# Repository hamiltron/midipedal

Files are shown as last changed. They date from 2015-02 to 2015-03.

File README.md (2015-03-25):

# Arduino One-Octave Foot Pedal MIDI Controller

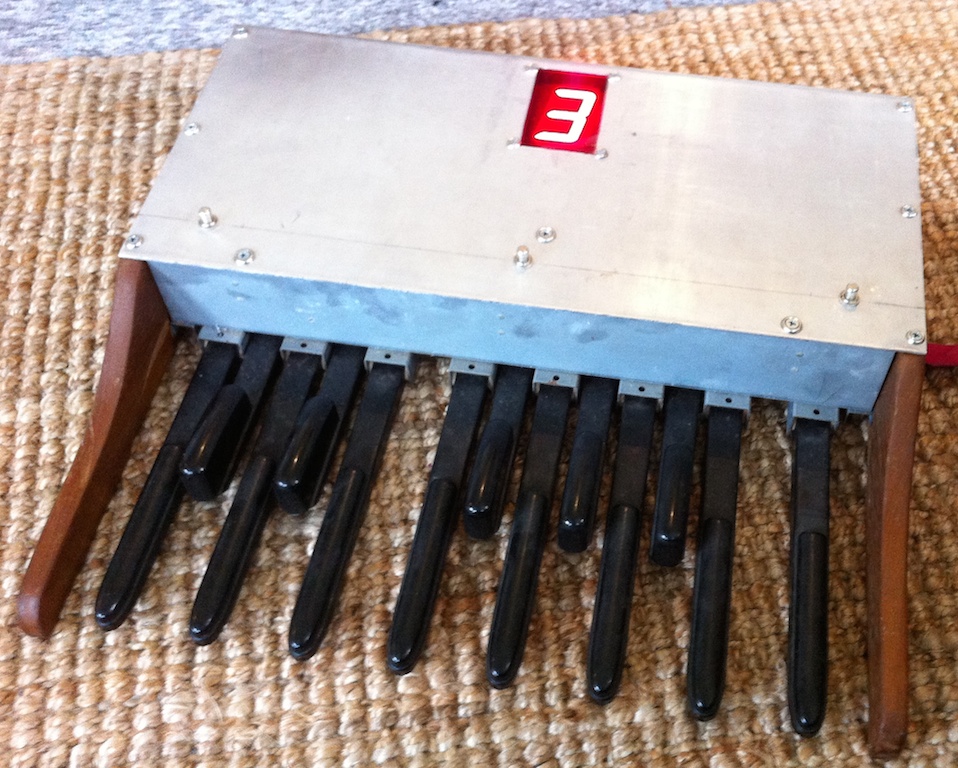
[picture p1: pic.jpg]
pic of pedal


## License

MIT

If you really need to rip this off for a commercial application, consider hiring me instead. :wink:

## Hardware 

I've written this for the [Arduino Micro](http://arduino.cc/en/Main/ArduinoBoardMicro). 
(Thus, the use of Serial1 for the MIDI output.) 

It has a one-octave foot pedal set 
with reed switches form a 70's era electronic organ. There are also an 'octave up', 'octave down', 
and 'configure' stomp switches, bringing the total switch count to 16 which makes for a tidy 4 x 4 
switch matrix. This uses the very nice [keypad library](http://playground.arduino.cc/Code/Keypad)
to manage the scanning and hold detection. In contrast to what is mentioned in the keypad 
documentation, diodes are a necessity for this type of application (one per switch) or you may get ghosting. 

There's a seven-segment display to show the octave and channel number. 
The decimal point is used to indicate polyphonic mode. 
The driver is the [TLC5916](http://www.ti.com/product/tlc5916) which is a snap to use over the SPI interface 
plus two extra Arduino outputs for the ~OE and LE pins. The current set resistor is 1K Ohm for 
approximately 20mA. 
The display I used is the Kingbright SA23-12SRWA which is about 6 cm high. It's nice and big and RED. 
**Rant**: Yes, blue LED's are new and therefore prejudicially cool, and red LED's are dusty old hat. 
But the reality 
is that human eyes disperse blue light more that red (the reason a lot of sunglasses have yellow tint) 
and these blue LED displays often have impressive 
luminosity which when combined, turn what would otherwise be a number into a fuzzy blue blob, 
leaving my microwave clock unreadable unless you're standing right in front of it. 

This seven segment display requires around 7.4 V to drive the segment diode strings, 
so we need a boost which is 
done with the old [MC34063](http://www.ti.com/product/mc34063a) (aka MC33063) 
which has very low frequency compared to modern switching regulators but there's a 
very nifty [part value calculator](http://www.nomad.ee/micros/mc34063a/). 
I doubled checked the calculated values with a spreadsheet based 
on the datasheet design equations and they all matched close enough for confidence. The intended output
voltage is about 9 V as this should give the needed 7.4 V for the LED's plus the TLC5916 output drop of 
about 1 V plus a small margin. This can be adjusted a bit if the display forward voltage deviates from 
the expected value. 

For the 5 V needed to drive the Atmel CPU, I decided to use the MCP1702 (5 V version) which supplies
a max current of 250 mA (completely fine for this application) with a typical dropout of 0.33 V. This is a 
much safer bet that using the onboard NCP1117 which has a spec'd dropout of 1.2 V 
(granted, at much higher currrent) and even though the CPU will probably run fine with a little less than 
5 V, having a roughly 0.4 V dropout gives much better margin of safety plus better mileage 
from the batteries. 

## UI

### Normal Mode

In any mode, the pedals trigger MIDI notes on the set octave and channel. In monophonic mode, the latest
pedal pressed triggers a note and the previous note is automatically silenced. In polyphonic mode, any 
number of notes may be triggered at once. (Technically this is not true as the keypad library keeps an
internal list of modified keys and it's default max size is ten, though this could easily be changed.) 
When in normal mode, the octave up and down switches move the octave and display is briefly on the 
display which also indicated whether or not polyphonic mode is enabled with the decimal point. 
Pressing the center 'configure' button briefly will also flash the display with the current channel.

**NOTE**: The octave and channel display (see below) are in zero-indexed hex, 
which departs from the convention of numbering MIDI channels 1 - 16, but this doesn't bother me
for personal uses so I'll leave it as such. 

### Configure Mode

If the configure button is held down for a few seconds, the controller will enter the configure mode, and the 
display will flash the current MIDI channel. Pressing the octave up and down buttons will change the 
MIDI channel and pressing the configure button will switch between polyphonic and monophonic mode
when the button is released. 
Pressing and holding the configure button will return to normal mode. 

### Non-Volatile Memory 

The current octave, channel, and poly/monophonic settings are stored in EEPROM each time they are
changed so the configuration is retained when the controller is switched off.

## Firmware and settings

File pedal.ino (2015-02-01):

#include <Keypad.h>
#include <EEPROM.h>
#include <SPI.h>

#define NOTE_OFF (0)
#define NOTE_ON  (1)

#define MONO (0)
#define POLY (1)

#define EE_ADDR_OCTAVE  (0)
#define EE_ADDR_POLY    (1)
#define EE_ADDR_CHANNEL (2)

#define VELOCITY (127)
#define HIGH_OCTAVE (9)

#define DOWN_BUTTON   (0x1D)
#define CONFIG_BUTTON (0x1E)
#define UP_BUTTON     (0x1F)

#define DEBOUNCE_MS     (10)
#define HOLD_MS         (2000)
#define FLASH_MS        (2000)
#define BLINK_PERIOD_MS (500)

#define TLC5916_OE (A5)
#define TLC5916_LE (A4)

// This utility macro function takes a key (0 = c, 1 = c#, 2 = b, etc) 
//   and the octave number and returns a valid midi note number
//   Not that for efficiency, it does not bounds check. 
#define MIDI_NOTE_NUM(key, octave) (key - 0x10 + 12 * octave)

enum states {
  NORMAL, 
  OCT_DOWN_PRESSED, 
  OCT_UP_PRESSED,
  CONFIG_PRESSED,
  CONFIG_WAIT_RELEASE,
  CONFIG,
  CHAN_DOWN_PRESSED,
  CHAN_UP_PRESSED,
  POLY_PRESSED,
  NORMAL_WAIT_RELEASE
};

enum flash_states {
  OFF,
  FLASH,
  BLINK_ON,
  BLINK_OFF
};

const char hex_character[] = {
  0x3F, 0x06, 0x5B, 0x4F, 0x66, 0x6D, 0x7D, 0x07,
  0x7F, 0x67, 0x77, 0x7C, 0x39, 0x5E, 0x79, 0x71
};

const char keys[4][4] = {
  {0x10, 0x11, 0x12, 0x13},
  {0x14, 0x15, 0x16, 0x17},
  {0x18, 0x19, 0x1A, 0x1B},
  {0x1C, 0x1D, 0x1E, 0x1F}
};
byte row_pins[4] = {6, 7, 8, 9}; 
byte col_pins[4] = {2, 3, 4, 5}; 
Keypad switches = Keypad(makeKeymap(keys), row_pins, col_pins, 4, 4);

byte note_status[128];
byte octave;
byte poly;
byte channel;
byte state;
byte seven_seg_state;
byte flash_state;
unsigned long flash_timeout;

void setup() {
  byte i;
  
  // turn off yellow LED
  pinMode(SS, INPUT);
  digitalWrite(SS, LOW);
  
  //  Set MIDI baud rate:
  Serial1.begin(31250);
  
  // initialize the note status array and status vars
  octave = EEPROM.read(EE_ADDR_OCTAVE);
  poly = EEPROM.read(EE_ADDR_POLY);
  channel = EEPROM.read(EE_ADDR_CHANNEL);
  for (i = 0; i < 128; i++) {
    note_status[i] = NOTE_OFF;
  }
  state = NORMAL;
  
  // handle cases where EEPROM gives erroneous values 
  //   (like when it's never been written to before)
  if (octave > HIGH_OCTAVE) {
    octave = 0;
    EEPROM.write(EE_ADDR_OCTAVE, octave);
  }
  if (channel > 0x0F) {
    channel = 0;
    EEPROM.write(EE_ADDR_CHANNEL, channel);
  }
  if (poly > 1) {
    poly = 0;
    EEPROM.write(EE_ADDR_POLY, poly);
  }
  
  // setup keypad class timings
  switches.setDebounceTime(DEBOUNCE_MS);
  switches.setHoldTime(HOLD_MS);
  
  // init TLC5916 interface and state
  SPI.begin();
  pinMode(TLC5916_OE, OUTPUT);
  digitalWrite(TLC5916_OE, HIGH);
  pinMode(TLC5916_LE, OUTPUT);
  digitalWrite(TLC5916_LE, LOW);
  write_digit(hex_character[octave]);
  write_dec_point(poly);
  
  // init seven seg flash timer and state
  flash_seven_seg();
}

void loop() {
  byte i;
  char kchar;
  char kstate;

  // check flash timeout
  if (flash_timeout != 0) {
    if (flash_timeout < millis()) {
      switch (flash_state) {
        case OFF:
          flash_timeout = 0;
          flash_state = OFF;
        break;
        case FLASH:
          flash_timeout = 0;
          digitalWrite(TLC5916_OE, HIGH);
          flash_state = OFF;
        break;
        case BLINK_ON:
          flash_timeout = millis() + BLINK_PERIOD_MS / 2;
          digitalWrite(TLC5916_OE, HIGH);
          flash_state = BLINK_OFF;
        break;
        case BLINK_OFF:
          flash_timeout = millis() + BLINK_PERIOD_MS / 2;
          digitalWrite(TLC5916_OE, LOW);
          flash_state = BLINK_ON;
        break;
      }
    }
  }
  
  // handle switches and buttons
  if (switches.getKeys()) {
    for (i = 0; i < LIST_MAX; i++) {
      if (switches.key[i].stateChanged) {
        kchar = switches.key[i].kchar;
        kstate = switches.key[i].kstate;

        // pedal note switches
        if (kchar < DOWN_BUTTON) {  
          if (kstate == PRESSED) {
            if (poly == MONO) {
              all_notes_off();
            }
            note_on(channel, MIDI_NOTE_NUM(kchar, octave), VELOCITY);
            note_status[MIDI_NOTE_NUM(kchar, octave)] = NOTE_ON;  
          } else if (kstate == RELEASED) {
            if (note_status[MIDI_NOTE_NUM(kchar, octave)] == NOTE_ON) {
              note_off(channel, MIDI_NOTE_NUM(kchar, octave));
              note_status[MIDI_NOTE_NUM(kchar, octave)] = NOTE_OFF;
            }
          }
          
        // octave up, octave down, config switches
        } else { 
          // state machine for stomp switch controls
          switch (state) {
            case NORMAL: 
              if (kstate == PRESSED) {
                switch (kchar) {
                  case DOWN_BUTTON:
                    octave_down();
                    write_digit(hex_character[octave]);
                    flash_seven_seg();
                    state = OCT_DOWN_PRESSED;
                  break;
                  case UP_BUTTON:
                    octave_up();
                    write_digit(hex_character[octave]);
                    flash_seven_seg();
                    state = OCT_UP_PRESSED;
                  break;
                  case CONFIG_BUTTON:
                    flash_seven_seg();
                    state = CONFIG_PRESSED;
                  break;
                }
              }
            break;
            case OCT_DOWN_PRESSED:
              if (kchar == DOWN_BUTTON && kstate == RELEASED) {
                state = NORMAL;
              }
            break;
            case OCT_UP_PRESSED:
              if (kchar == UP_BUTTON && kstate == RELEASED) {
                state = NORMAL;
              }
            break;
            case CONFIG_PRESSED:
              if (kchar == CONFIG_BUTTON) {
                if (kstate == HOLD) {
                  write_digit(hex_character[channel]);
                  blink_seven_seg();
                  state = CONFIG_WAIT_RELEASE;
                } else if (kstate == RELEASED) {
                  state = NORMAL;
                }
              }
            break;
            case CONFIG_WAIT_RELEASE:
              if (kchar == CONFIG_BUTTON && kstate == RELEASED) {
                state = CONFIG;
              }
            break;
            case CONFIG:
              if (kstate == PRESSED) {
                switch (kchar) {
                  case DOWN_BUTTON:
                    channel_down();
                    write_digit(hex_character[channel]);
                    state = CHAN_DOWN_PRESSED;
                  break;
                  case UP_BUTTON:
                    channel_up();
                    write_digit(hex_character[channel]);
                    state = CHAN_UP_PRESSED;
                  break;
                  case CONFIG_BUTTON:
                    state = POLY_PRESSED;
                  break;
                }
              }
            break;
            case CHAN_DOWN_PRESSED:
              if (kchar == DOWN_BUTTON && kstate == RELEASED) {
                state = CONFIG;
              }
            break;
            case CHAN_UP_PRESSED:
              if (kchar == UP_BUTTON && kstate == RELEASED) {
                state = CONFIG;
              }
            break;
            case POLY_PRESSED:
              if (kchar == CONFIG_BUTTON) {
                if (kstate == RELEASED) {
                  toggle_poly();
                  write_dec_point(poly);
                  state = CONFIG;
                } else if (kstate == HOLD) {
                  write_digit(hex_character[octave]);
                  flash_seven_seg();
                  state = NORMAL_WAIT_RELEASE;
                }
              }
            break;
            case NORMAL_WAIT_RELEASE:
              if (kchar == CONFIG_BUTTON && kstate == RELEASED) {
                state = NORMAL;
              }
            break;
          }
        }
      }
    }
  }
}

// continuous rapid blinking
void blink_seven_seg() {
  flash_timeout = millis() + BLINK_PERIOD_MS / 2;
  digitalWrite(TLC5916_OE, LOW);
  flash_state = BLINK_ON;
}

// one-shot flash of longer duration
void flash_seven_seg() {
  flash_timeout = millis() + FLASH_MS;
  digitalWrite(TLC5916_OE, LOW);
  flash_state = FLASH;
}

// write the seven segment digit preserving the decimal point
void write_digit(byte digit) {
  seven_seg_state = (seven_seg_state & 0x80) | (digit & 0x7F);
  SPI.transfer(seven_seg_state);
  digitalWrite(TLC5916_LE, HIGH);
  digitalWrite(TLC5916_LE, LOW);
}

// write the seven segment decimal preserving the digit
void write_dec_point(byte dec_point) {
  seven_seg_state = (seven_seg_state & 0x7F) | (dec_point << 7);
  SPI.transfer(seven_seg_state);
  digitalWrite(TLC5916_LE, HIGH);
  digitalWrite(TLC5916_LE, LOW);
}

void octave_down() {
  all_notes_off();
  if (octave > 0) {
    octave--;
    EEPROM.write(EE_ADDR_OCTAVE, octave);
  }
}

void octave_up() {
  all_notes_off();
  if (octave < HIGH_OCTAVE) {
    octave++;
    EEPROM.write(EE_ADDR_OCTAVE, octave);
  }
}

void channel_down() {
  all_notes_off();
  if (channel > 0) {
    channel--;
    EEPROM.write(EE_ADDR_CHANNEL, channel);
  }
}

void channel_up() {
  all_notes_off();
  if (channel < 0x0F) {
    channel++;
    EEPROM.write(EE_ADDR_CHANNEL, channel);
  }
}

void toggle_poly() {
  all_notes_off();
  poly = !poly;
  EEPROM.write(EE_ADDR_POLY, poly);
}

// turn off all notes flagged as having been turned on
void all_notes_off() {
  byte j;
  for (j = 0; j < 128; j++) {
    if (note_status[j] == NOTE_ON) {
      note_off(channel, j);
      note_status[j] = NOTE_OFF;                
    }
  }
}

// send MIDI note-on message
void note_on(byte channel, byte pitch, byte velocity) {
  Serial1.write(0x90 | (channel & 0x0F));
  Serial1.write(pitch & 0x7F);
  Serial1.write(velocity & 0x7F);
}

// send MIDI note-off message
void note_off(byte channel, byte pitch) {
  Serial1.write(0x80 | (channel & 0x0F));
  Serial1.write(pitch & 0x7F);
  Serial1.write(127); // velocity
}

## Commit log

2015-01-08 initial commit of code, fixed license
    [pedal.ino]
2015-01-23 changed ~OE and LE pin assignments for final design. updated readme.md
2015-01-31 fixed bad switch ID
    [pedal.ino]
2015-02-01 fixed bug related to having a key char with a numerical value of zero. also fixed yellow LED on SS line staying on.
    [pedal.fzz]
2015-03-24 removed Fritzing sketch
    [pedal.fzz]
